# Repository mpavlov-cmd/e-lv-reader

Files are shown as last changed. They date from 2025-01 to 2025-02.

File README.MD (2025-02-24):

# ESP32 E-Reader Project 
Opensource ESP-32 EPaper Display Device

## Discalimer
Project comes with ABSOLUTELY NO WARRANTY. Author is not responsible for any damage made to individuals or their property while attempting to build or/and use the product.

## Features
### Hardware
> [!NOTE]
> Schematic, gerber and 3mf files for building PCB and housing are availble under `hardware` folder of the repository.

- Popular and cheap ESP32 platform.
- Big 800x480 Good Display GDEQ0426T82 E-Paper SPI Diaplay.
- USB-C power, charing and firmware upload.
- Micro SD Card support (SPI Interface).
- Low power consumption: ~2mA in sleep mode.
- Optinal JTAG connector for debug purposes.
- External clock crystal for accurate time. 
- Ability to control external hardware e.g., backlight.
- Power and battery level dtection.
- All components available on aliexpress almost for free.
- 30th/15th vias for lowering PCB manufaturing cost.

> [!WARNING]
> Currently the project is using external DESPI-C02 driver board for interfacing with EPD.
> This will potentially be changed in the further implementations as external driver board does not allow to make thin housing design.

### Bill Of Materials
[BOM CSV](https://github.com/mpavlov-cmd/e-lv-reader/blob/main/hardware/bom/BOM_rev1.0.0.csv)

### Software
- PlatformIO, Arduino Framework.
- LVGL driver for GDEQ0426T82 display with partial refresh, 2 buffers and partial rendering support.
- MVC framework featuring abstract Intent and Widget concepts.

## Pictures
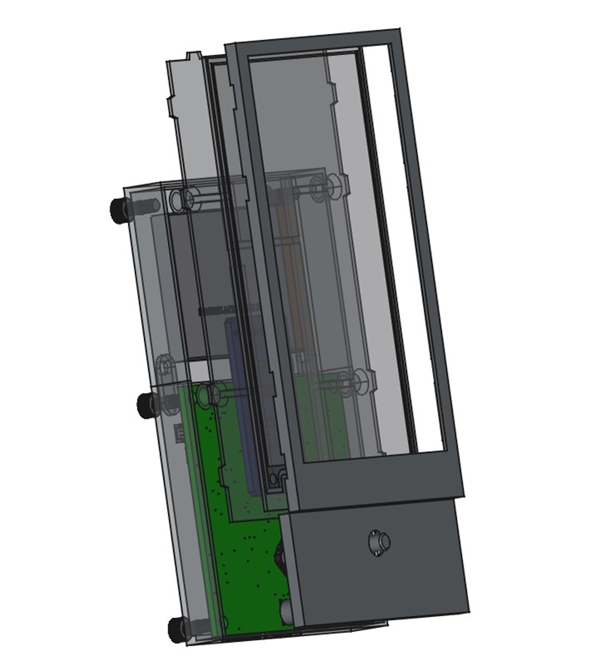
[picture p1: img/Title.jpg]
Housing

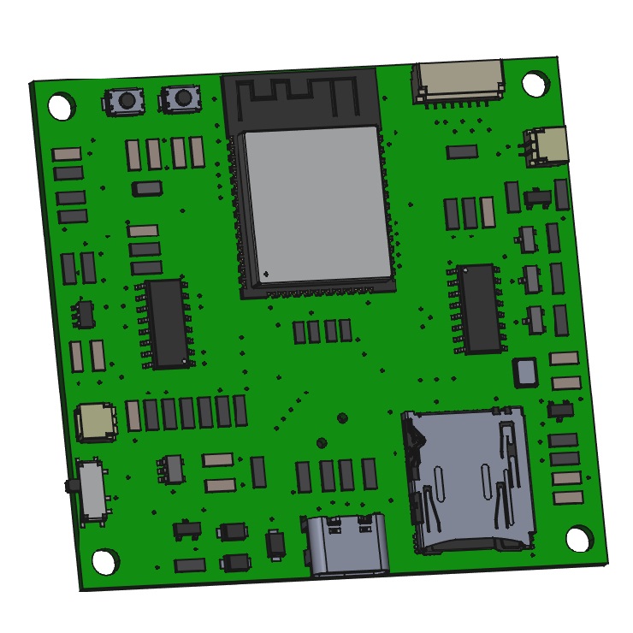
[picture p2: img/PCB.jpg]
PCB


## Software Used
- [Labcenter Proteus](https://www.labcenter.com/)
- [FreeCAD](https://www.freecad.org/)
- [Platform IO](https://platformio.org/)
- [Visual Studio Code](https://code.visualstudio.com/download)

## Special Thanks
- [Andre' Lamothe](https://www.udemy.com/course/crash-course-electronics-and-pcb-design/?couponCode=JUST4U02223) for sharing his passion for electronics with so many people
- [Ben Eater](https://eater.net/)
- [@MangoJellySolutions](https://www.youtube.com/@MangoJellySolutions) for a great FreeCAD course

# Project Notes

## No PSRAM Support
- Chip Used: ESP32-D0WD-V3
- Chip with PSRAM: ESP32-D0WDR2-V3 (R - has ram, 2 - size in megs)

## Log Levels
```ini
build_flags =
    ; ESP Log level
    -D CORE_DEBUG_LEVEL=4
```

## Supported 8 Bit BMPs
Set `lv_conf.h` parameter, in my case in `platfromio.ini`:
```ini
build_flags =
    -D LV_COLOR_DEPTH=8
```
Converting image with GIMP:

- Use Image -> Mode -> Indexed with 256 colours and dithering if needed.
- Export as a filename.bmp, the Advanced Options are greyed out.
- Depending on purpose you might need to toggle color space info on/off.

## TODO List
### Software
- [ ] Further adjust README.MD further
### Hardware
- [ ] Implement diff pairs for USB
- [ ] Move battery, backlight Connectos, so they do not interfere with housing 
- [ ] Integrate DESPI-C02 into PCB
- [ ] Position ESP-32 chip so the antenna is placed outside of the board

## WIKI
 - Display: 800x480  
 - `pio test -vv` will show serial moitor output 
 - `pio test -vv -f "test_textIndex"` filter tests based on a directory
 - [Battery Sense](https://github.com/rlogiacco/BatterySense?tab=readme-ov-file)
 - [SD Card](https://github.com/espressif/arduino-esp32/tree/master/libraries/SD)
 - [Interrupts](https://www.youtube.com/watch?v=CJhWlfkf-5M)
 - [Sleep](https://randomnerdtutorials.com/esp32-deep-sleep-arduino-ide-wake-up-sources/)

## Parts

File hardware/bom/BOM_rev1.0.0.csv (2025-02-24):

Category | Quantity | References | Value | PCB Package
Capacitors | 1 | C1 | 470pF | 1206_CAP
Capacitors | 1 | C2 | 2.2uF | 1206_CAP
Capacitors | 2 | C3-C4 | 4.7uF | 1206_CAP
Capacitors | 4 | C5-C6,C9-C10 | 12pF | 1206_CAP
Capacitors | 4 | C7,C13,C15,CJ1 | 0.1uF | 1206_CAP
Capacitors | 1 | C8 | 10nF | 1206_CAP
Capacitors | 3 | C11-C12,C14 | 10uF | 1206_CAP
Resistors | 2 | R1-R2 | 33R | 1206_RES
Resistors | 2 | R3-R4 | 5.1K | 1206_RES
Resistors | 2 | R5,R15 | 200R | 1206_RES
Resistors | 14 | R6,R9-R11,R13-R14,R16,RB3,RJ1-RJ6 | 10K | 1206_RES
Resistors | 2 | R7,R12 | 2.4K | 1206_RES
Resistors | 1 | R8 | 2.4k | 1206_RES
Resistors | 4 | R26-R29 | 100R | 0805_RES
Resistors | 4 | RB1-RB2,RP2-RP3 | 1M | 1206_RES
Resistors | 1 | RP1 | 5K | 1206_RES
Resistor Charge Current | 1 | R_CH | 4K | 1206_RES
Integrated Circuits | 1 | U1 | ESP32WROOM32 | ESP32WROOM32
Integrated Circuits | 1 | U2 | MIC5219-3,3YM5 | SOT-23-5
Integrated Circuits | 1 | U3 | MCP73831T2ACIOT | SOT-23-5
Integrated Circuits | 1 | U4 | CH340G | SO16
Integrated Circuits | 1 | U5 | 74HC148 | SO16
Transistors | 1 | Q1 | SI2301 | SOT23
Transistors | 2 | Q2,Q6 | SI2302DS | SOT23
Transistors | 3 | Q3-Q5 | MMBT2222A | SOT23
Diodes | 2 | D1-D2 | 1N4007 | SOD-123
Diodes | 1 | D3 | LED-RED | SOD-123
Connectors | 1 | J1 | Molex 217179-0001 | MOLEX 217179-0001
Connectors | 1 | J2 | JST SH 1.0 | SH 1.0 8P
Connectors | 1 | J3 | JST SH 1.0 | SH 1.0 5P
Connectors | 1 | J4 | DM3ATSFPEJM5 | HRS_DM3ATSFPEJM5
Connectors | 1 | J5 | JST SH 1.0 | SH 1.0 2P
Connectors | 1 | JTAG | JST SH 1.0 | SH 1.0 5P
Miscellaneous | 1 | B1 | 3.7V | SH 1.0 2P
Miscellaneous | 2 | BOOT,RST | SW-SPST-MOM | SMD SWITCH 3X4
Miscellaneous | 1 | SW1 | MSK12C02 | MSK12C02
Miscellaneous | 1 | SW2 | SKRHABE010 | SKRHABE010
Miscellaneous | 1 | X1 | CRYSTAL | CRYSTAL FC135
Miscellaneous | 1 | X2 | CRYSTAL | CRYSTAL 3225

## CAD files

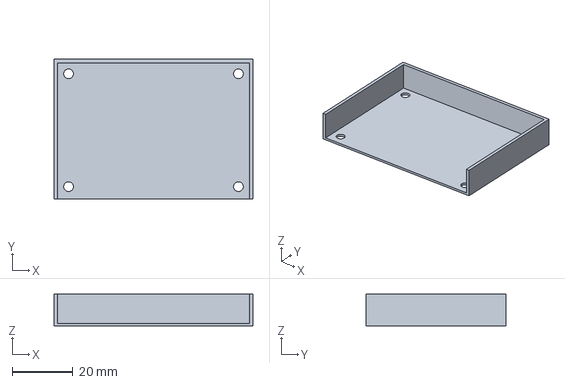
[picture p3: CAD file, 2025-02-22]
hardware/housing/V1.0.0/HousingMaster-CredleBottom2.3mf
65.6 x 46.0 x 10.4 mm

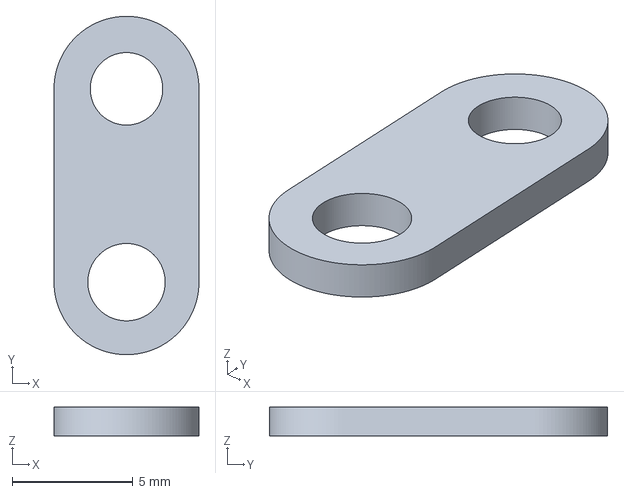
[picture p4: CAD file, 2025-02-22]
hardware/housing/V1.0.0/HousingMaster-CredleJoint1.3mf
6.00 x 14.0 x 1.20 mm

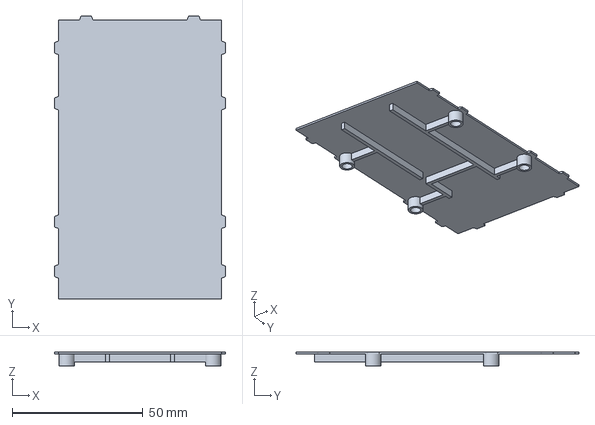
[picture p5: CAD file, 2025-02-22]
hardware/housing/V1.0.0/HousingMaster-ScreenCoverBottom.3mf
65.6 x 108.4 x 5.40 mm

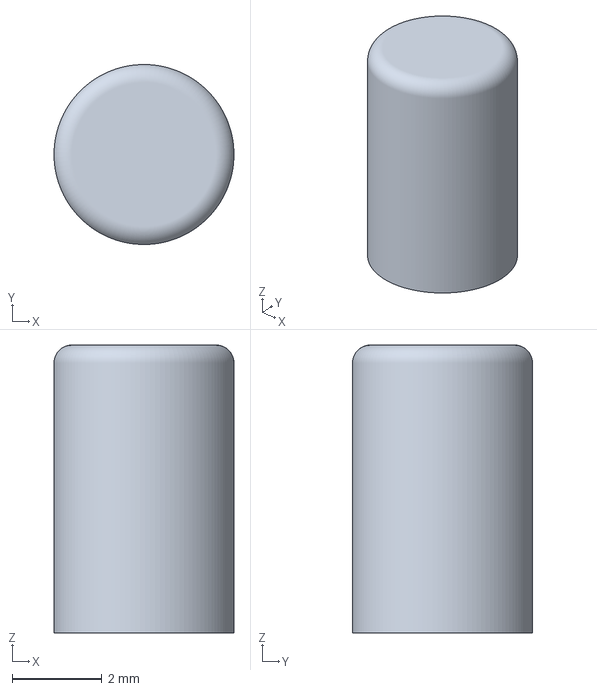
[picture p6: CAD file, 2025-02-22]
hardware/housing/V1.0.0/HousingMaster-JoystickHat.3mf
4.00 x 4.00 x 6.40 mm

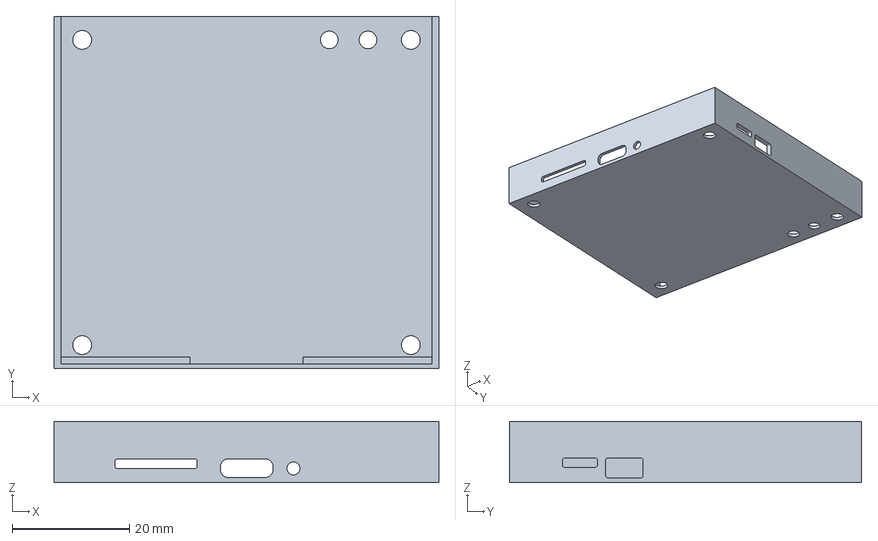
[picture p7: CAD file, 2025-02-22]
hardware/housing/V1.0.0/HousingMaster-CredleBottom1.3mf
65.6 x 60.0 x 10.4 mm

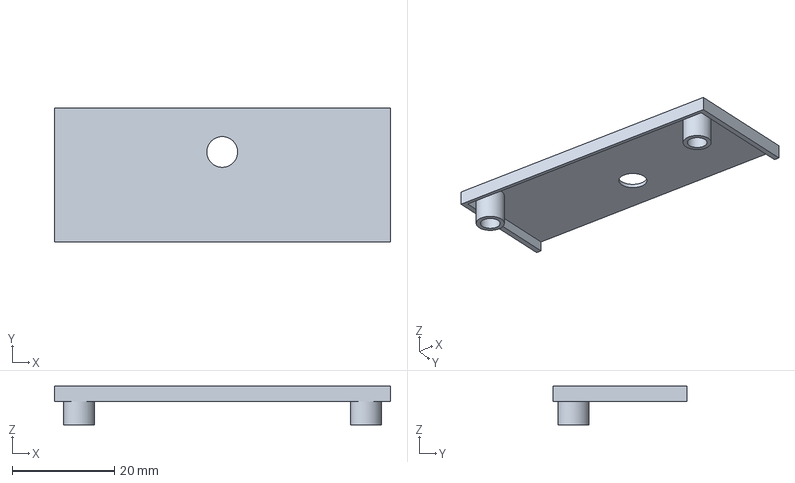
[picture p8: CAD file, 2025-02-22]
hardware/housing/V1.0.0/HousingMaster-PCBCoverTop.3mf
65.6 x 26.2 x 7.60 mm

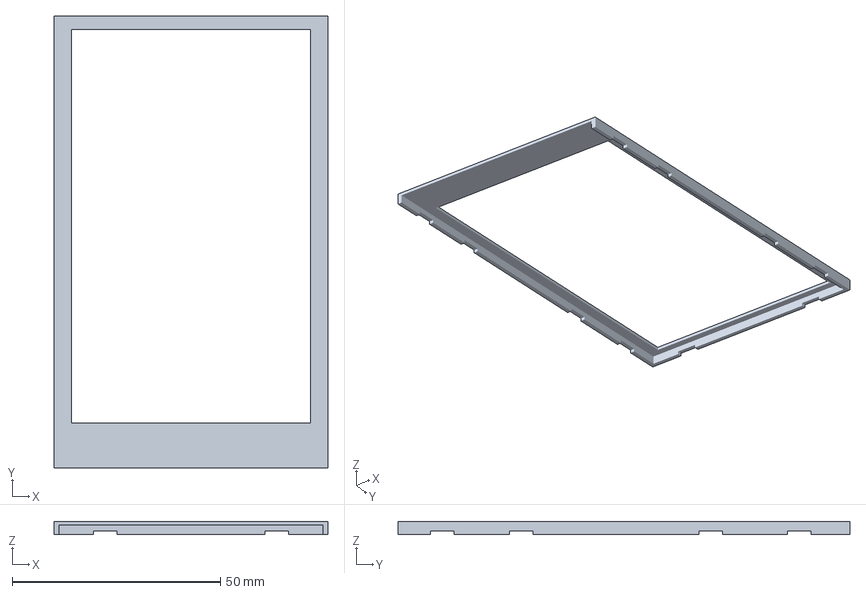
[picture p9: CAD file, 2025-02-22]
hardware/housing/V1.0.0/HousingMaster-ScreenCoverTop.3mf
65.6 x 108.4 x 3.00 mm

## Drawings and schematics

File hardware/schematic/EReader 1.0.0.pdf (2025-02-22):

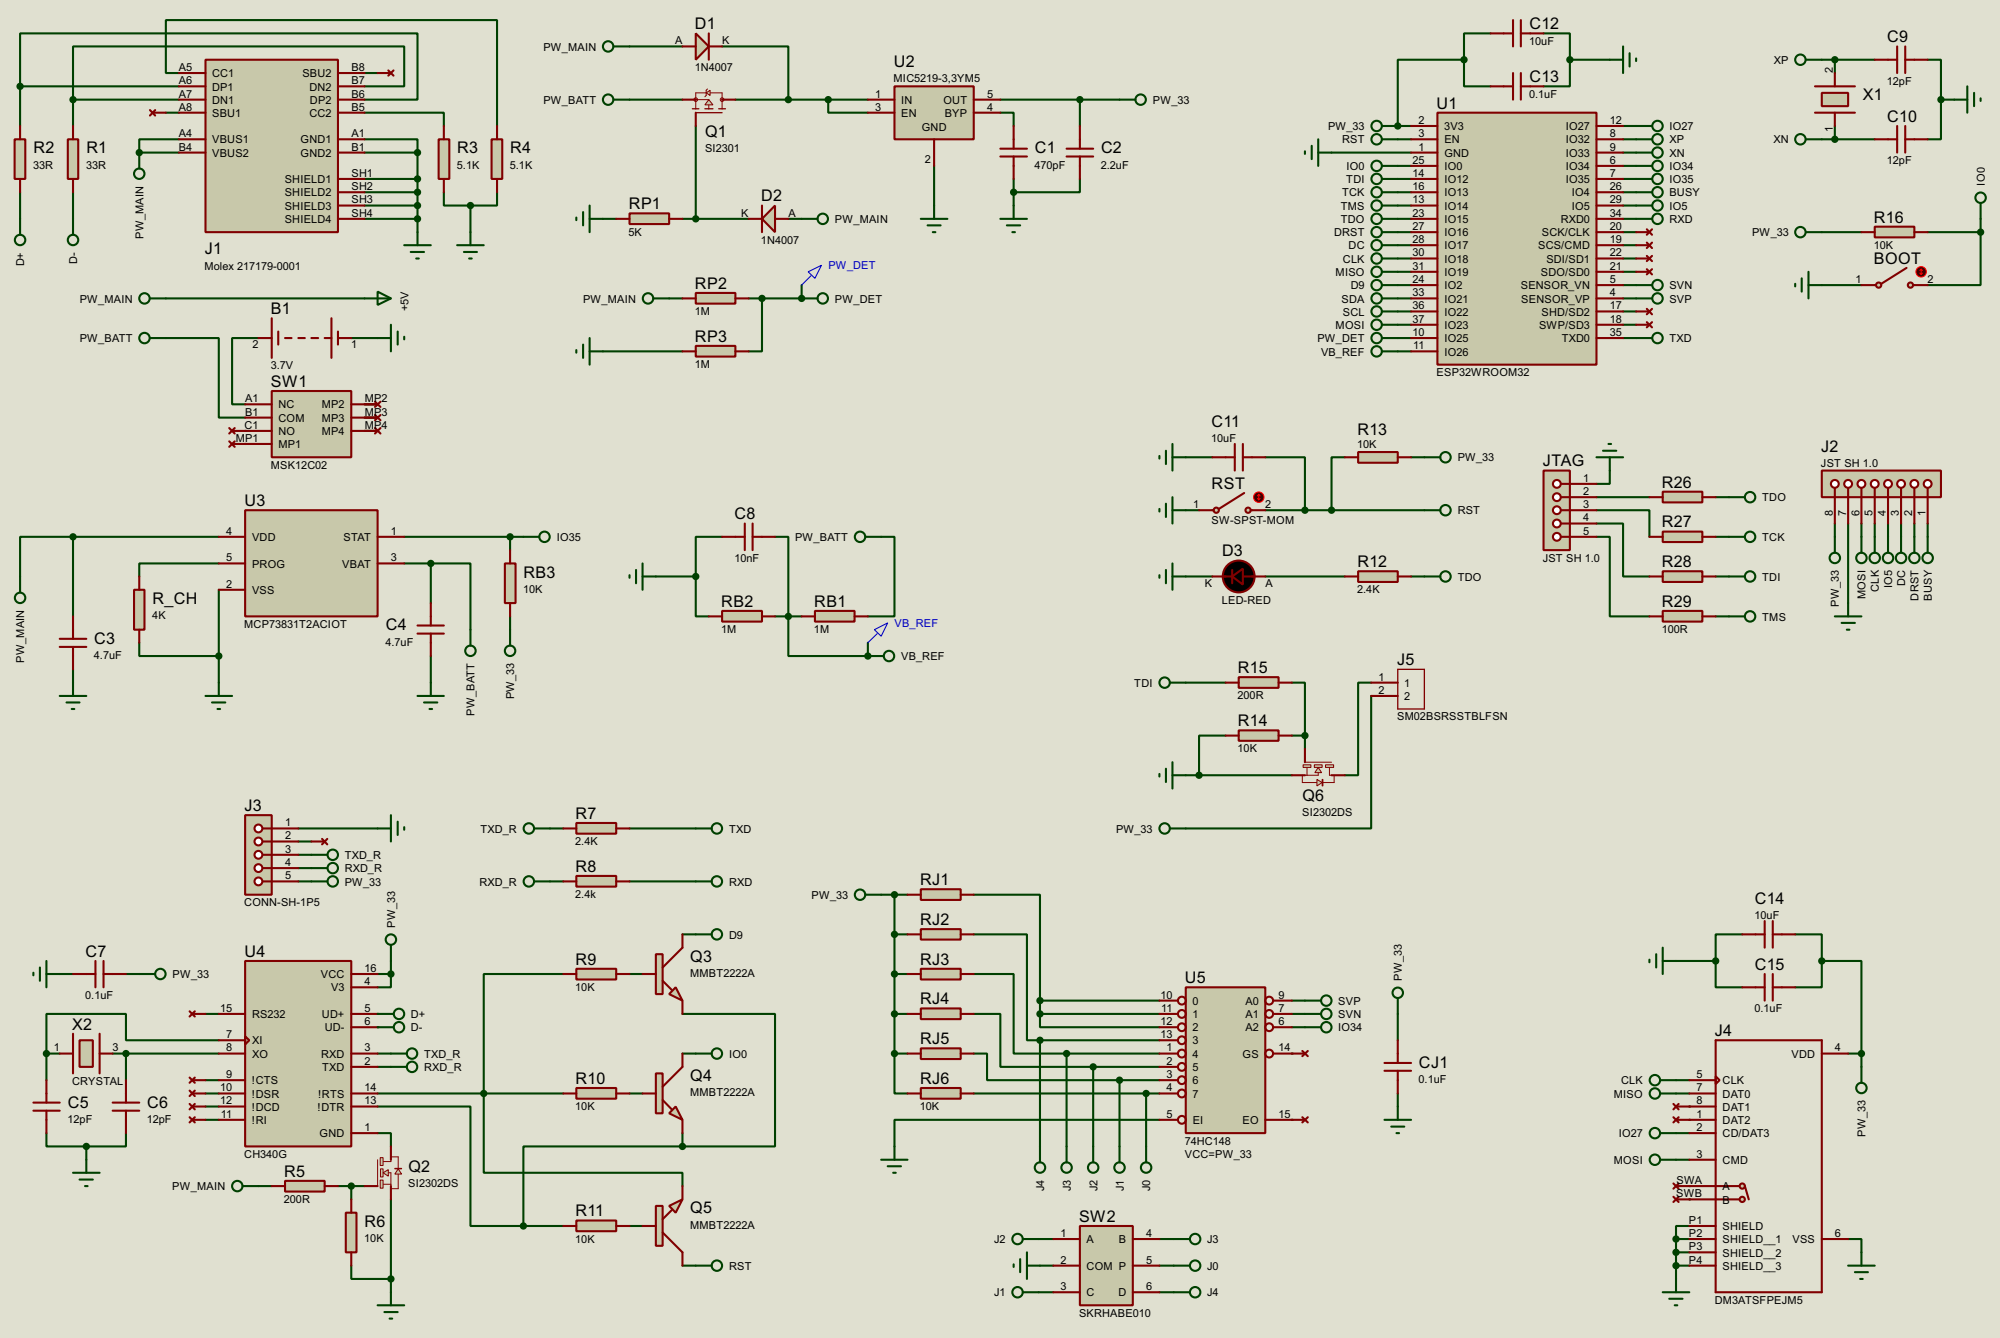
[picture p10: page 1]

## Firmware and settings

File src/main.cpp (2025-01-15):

#ifndef PIO_UNIT_TESTING

#include "lvgl.h"
#include "app_hal.h"
#include "esp_log.h"
#include "LogTags.h"

#ifdef ARDUINO
#include <Arduino.h>

void setup()
{
    Serial.begin(115200);
	ESP_LOGI(TAG_MAIN, "----- BOOT SUCCESS -----");
    ESP_LOGI(TAG_MAIN, "Chip Name: %s", ESP.getChipModel());
	
	hal_setup();
}

void loop()
{
	// Do not use while loop in this function
	hal_loop();  
}

#else

int main(void)
{
	lv_init();

	hal_setup();

	lv_demo_widgets();

	hal_loop();
}

#endif // ARDUINO
#endif // PIO_UNIT_TESTING

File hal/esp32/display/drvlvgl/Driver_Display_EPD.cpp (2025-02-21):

#include "Driver_Display_EPD.h"

#include <Arduino.h>
#include <SPI.h>
#include "lvgl.h"
#include "LogTags.h"
#include "esp_log.h"

#include "PinDefinitions.h"
#include "drvspi/Display_EPD_W21_spi.h"
#include "drvspi/Display_EPD_W21.h"

// Strct definiton
struct BufferData {
    unsigned char* buffer;  // Pointer to the buffer
    int x;                  // x-coordinate
    int y;                  // y-coordinate
    int width;              // Width of the buffer
    int height;             // Height of the buffer
};

// Function definitions
void epd_flush_cb(lv_disp_drv_t * disp_drv, const lv_area_t * area, lv_color_t * color_p);
void epd_rounder_cb(lv_disp_drv_t * disp_drv, lv_area_t * area);

// void epd_flush_cb_new(lv_disp_drv_t * disp_drv, const lv_area_t * area, lv_color_t * color_p);
void epd_set_px_cb_new(struct _lv_disp_drv_t * disp_drv, uint8_t * buf, lv_coord_t buf_w, lv_coord_t x, lv_coord_t y,
    lv_color_t color, lv_opa_t opa);

void tick_timer_callback(void *arg);

#define MY_DISP_MAX_BUFFERS 35

#ifndef MY_DISP_HOR_RES
#define MY_DISP_HOR_RES 480
#endif

#ifndef MY_DISP_VER_RES
#define MY_DISP_VER_RES 800
#endif

// Display variables
// Static or global buffer(s). The second buffer is optional
static lv_disp_draw_buf_t draw_buf_dsc_1;
static lv_color_t buf_1[MY_DISP_HOR_RES * 32];
static lv_color_t buf_2[MY_DISP_HOR_RES * 32];

static lv_disp_drv_t disp_drv; 
static lv_disp_t* disp;   

uint16_t chunkCounter = 0;
bool forceDispRefresh = false;

static BufferData* bufferCollection = nullptr;
int bufferCount = 0; // To track the number of stored buffers

/**
 * Requires SPI to be initialized 
 */
void lv_epd_disp_init(void)
{
    // Set display pins
    pinMode(PIN_DISP_BUSY, INPUT);
    pinMode(PIN_DISP_RST,  OUTPUT);
    pinMode(PIN_DISP_DC,   OUTPUT); 
    pinMode(PIN_DSIP_CS,   OUTPUT);

    // Full screen refresh initialization and set buffer for patial refresh should be triggered by 
    // lv_epd_mark_full during first display init or in tests

    // EPD_HW_Init_Fast();          
    // EPD_SetRAMValue_Empty_BaseMap();

    // ----- DISPLAY DRIVER INIT START -----

    // ------ Start display config ------
    lv_disp_draw_buf_init(&draw_buf_dsc_1, buf_1, buf_2, MY_DISP_HOR_RES * 32);  
    lv_disp_drv_init(&disp_drv);                   

    /*Set up the functions to access to your display*/

    // Set the resolution of the display
    disp_drv.hor_res = MY_DISP_HOR_RES;
    disp_drv.ver_res = MY_DISP_VER_RES;
    // disp_drv.direct_mode = 1;

    // Used to copy the buffer's content to the display*/
    disp_drv.flush_cb = epd_flush_cb;
    disp_drv.rounder_cb = epd_rounder_cb;
    disp_drv.set_px_cb = epd_set_px_cb_new;

    disp_drv.draw_buf = &draw_buf_dsc_1;

    // Get pointer to the active display 
    disp = lv_disp_drv_register(&disp_drv);

    // Lunch tick timer for display refreh
    // Set up the tick timer
    const esp_timer_create_args_t tick_timer_args = {
        .callback = &tick_timer_callback,
        .name = "lv_tick_timer"
    };
    esp_timer_handle_t tick_timer;
    esp_timer_create(&tick_timer_args, &tick_timer);
    esp_timer_start_periodic(tick_timer, 1000); // 1ms interval
}

void lv_epd_mark_full(void)
{
    forceDispRefresh = true;
}

// Display flushing 
// In Driver: 0X00 - Black; 0XFF: White (Every value contains 8 bits)
// In Driver: Each next char fills pixel: X0Y0, X0Y1, X0Y2, X0Y3

// Example of the working configuration
// https://github.com/lvgl/lvgl_esp32_drivers/blob/master/lvgl_tft/uc8151d.c#L211
// Initial example working now
// https://github.com/lvgl/lv_platformio/blob/master/platformio.ini
// Full documentation on proting
// https://docs.lvgl.io/8/porting/display.html#examples
void epd_flush_cb(lv_disp_drv_t * disp_drv, const lv_area_t * area, lv_color_t * color_p)
{
    ESP_LOGV(TAG_DISPL, "--- Flush Start ---");
    SPI.beginTransaction(SPISettings(10000000, MSBFIRST, SPI_MODE0));

    int width = lv_area_get_width(area);
    int height = lv_area_get_height(area);

    ESP_LOGV(TAG_DISPL, "Width and height: %ix%i", width, height);
    ESP_LOGV(TAG_DISPL, "Start pos: %ix%i", area->x1, area->y1);

    ESP_LOGV(TAG_DISPL, "--- Before RAM ---");
    if (chunkCounter == 0)
    {
        ESP_LOGD(TAG_DISPL, "--- Initial Update ---");
        if (forceDispRefresh) {
            EPD_HW_Init_Fast();
            EPD_SetRAMValue_Empty_BaseMap();
            forceDispRefresh = false;
        }

        bufferCollection = new BufferData[MY_DISP_MAX_BUFFERS];
    }

    ESP_LOGV(TAG_DISPL, "--- x1,y1: %ix%i width: %i, height: %i ---", area->x1, area->y1, width, height);

    EPD_Dis_Part_RAM(0x24, area->y1, area->x1, (uint8_t*) color_p, width, height);
    chunkCounter++;

    // Prepare the buffer and add it to collection:
    unsigned char* epd_buffer = new unsigned char[(width * height) / 8];
    memcpy(epd_buffer, color_p, (width * height) / 8);

    ESP_LOGV(TAG_DISPL, "Size of buffer: %i", sizeof(epd_buffer));

    // Add buffer to collection:
    bufferCollection[bufferCount++] = {epd_buffer, area->x1, area->y1, width, height};
    ESP_LOGV(TAG_DISPL, "Added buffer to collection: %i", bufferCount);

    if (lv_disp_flush_is_last(disp_drv)) {

        // Update display with already stored display data
        EPD_Part_Update();

        // Fill buffers for next refresh
        for (int i = 0; i < bufferCount; i++) {
            ESP_LOGV(TAG_DISPL, "Writhing stored buffer data forthe next operation: %i", i);

            BufferData cbd = bufferCollection[i];
            EPD_Dis_Part_RAM(0x26, cbd.y, cbd.x, cbd.buffer, cbd.width, cbd.height);
            EPD_Dis_Part_RAM(0x24, cbd.y, cbd.x, cbd.buffer, cbd.width, cbd.height);

            ESP_LOGV(TAG_DISPL, "Deleting buffer from collection: %i", bufferCount);
            delete[] bufferCollection[i].buffer;
        }

        delete[] bufferCollection;
        bufferCollection = nullptr;
        chunkCounter = 0;
        bufferCount  = 0;

        EPD_DeepSleep();
        ESP_LOGD(TAG_DISPL, "--- Flush completed ---");
    }
    
    // Anyway tell lgvl that display is ready
    SPI.endTransaction();
    lv_disp_flush_ready(disp_drv); /* tell lvgl that flushing is done */
}

void epd_rounder_cb(lv_disp_drv_t *disp_drv, lv_area_t *area)
{
    // Round the x1 coordinate down to the nearest multiple of 8
    area->x1 = (area->x1 / 8) * 8;
    // Round the x2 coordinate up to the nearest multiple of 8
    area->x2 = ((area->x2 + 7) / 8) * 8 - 1;
    // Round the y1 coordinate down to the nearest multiple of 8
    area->y1 = (area->y1 / 8) * 8;
    // Round the y2 coordinate up to the nearest multiple of 8
    area->y2 = ((area->y2 + 7) / 8) * 8 - 1;
}

void tick_timer_callback(void *arg) {
    // Increment LVGL tick by 1 ms
    lv_tick_inc(1); 
}
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

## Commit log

2025-01-01 Downgraded lvgl to be able to override driver functions for epd
2025-01-02 Moved display init to the driver
2025-01-02 Moved keypad driver to a separate file
2025-01-02 Moved timer to a separate lib and configured ESP log
2025-01-04 Moved power and battery libs
2025-01-05 Implemented actions and intent switch
2025-01-05 Moved timer handler to the ui thread
2025-01-06 Added widget text fixed menu padding and reated slip flow. TODO: Add widgt image
    [Driver_Display_EPD.cpp, app_hal.cpp]
2025-01-07 Reforat code for driver
2025-01-08 Added second buffer. Added code temlate for future override set_px_cb. Changed log level on display driver to verbose.
2025-01-09 Partially ported intent book, fixed imports moved event group int to abstract intent
    [app_hal.cpp]
2025-01-09 Configured actions retreval for all buttons in text widget.
2025-01-13 Enchanced driver partial update and other changes
2025-01-13 Reworked widget status. Cleanup for driver
    [Driver_Display_EPD.cpp]
2025-01-14 Migrated hardware staff, proper refresh for StatusManager
    [EReader - CADCAM Bottom Copper.GBR, EReader - CADCAM Bottom SMT Paste.GBR, EReader - CADCAM Bottom Silk Screen.GBR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]
2025-01-16 Sleep flow iproved to wake up on timer
2025-01-18 Added Intent and Widget for configuration. Markup and button actions. TODO: Save and validation
2025-01-18 Added event listener for dropdown change and pre-set values to clock widget based on current time. Flawles!
2025-01-20 Fixed issue with status manager after sllep on timeout
    [app_hal.cpp]
2025-01-20 Fixed test and small corner case handling
2025-01-24 TOOD Resolved, pin changes for LED and Backlight
2025-02-19 Adjusted pin def based on the new PCB
2025-02-21 Driver with set_px_cb implemented
2025-02-22 Added housing, schematic and gerber for v1.0.0
    [EReader_rev2.3 - CADCAM Bottom Assembly.GBR, EReader_rev2.3 - CADCAM Bottom Copper.GBR, EReader_rev2.3 - CADCAM Bottom SMT Paste.GBR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]
2025-02-23 Applied mono theme to avoid manual style override for EPD
    [app_hal.cpp]
2025-02-24 Added BOM
    [BOM_rev1.0.0.csv]
2025-02-24 Added BOM Link to README.MD
